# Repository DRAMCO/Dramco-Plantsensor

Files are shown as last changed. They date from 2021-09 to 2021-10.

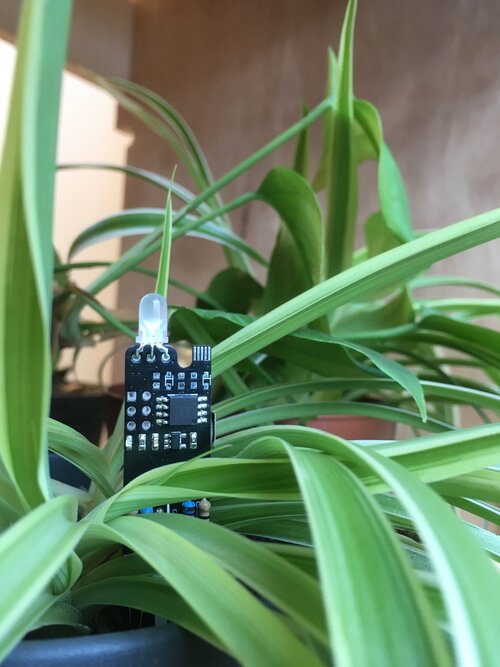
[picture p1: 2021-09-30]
Hardware/Pictures/Picture 2.jpg

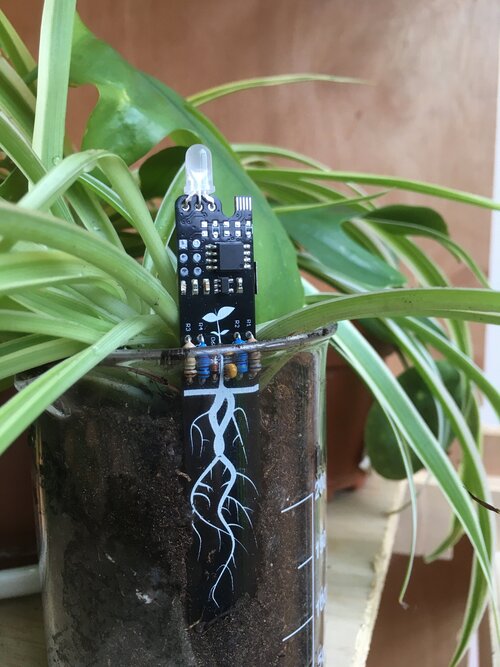
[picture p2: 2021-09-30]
Hardware/Pictures/Picture 1.jpg

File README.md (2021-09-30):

# Dramco Plantsensor
Blinking plant sensor

## How it works
The Dramco Plantsensor measures the moisture level of the soil every 30 seconds. When the soil is dry, the green LED will start blinking (first rapidly to get your attention, after a while it will slow down to every 30 seconds). The battery is running low when the red LED also starts blinking. If you have the rechargeable version, you can recharge using the micro USB connection on top. If not, replace the battery (you can also power the sensor of a USB cable). 

## How to assemble
When you get your Dramco Plantsensor, some components still need to be soldered. Solder all through hole components to complete the sensor. More information in this pdf. Don't forget to add a battery. 

## How to program
To program the Dramco Plantsensor, you'll need a [Dramco Uno as ATTINY85 programmer](https://create.arduino.cc/projecthub/arjun/programming-attiny85-with-arduino-uno-afb829), some [POGO pins](https://benl.rs-online.com/web/p/test-pins/1613648/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) and the [Arduino IDE](https://www.arduino.cc/en/software) installed. The pinout of the programming pads, is shown in the schematics. Adapt and use the following command to program: 
 ```
 "C:\Program Files (x86)\Arduino\hardware\tools\avr/bin/avrdude" -C"C:\Program Files (x86)\Arduino\hardware\tools\avr/etc/avrdude.conf" -v -pattiny85 -cstk500v1 -PCOM4 -b19200 -Uflash:w:"Soil_sensor.hex":i -U lfuse:w:0xF1:m -U hfuse:w:0x57:m -U efuse:w:0xFE:m
 ```
(!) This command disables the RESET pin of the ATTINY85, use only if you have a [high voltage flash programmer](https://td0g.ca/2020/04/13/high-voltage-flash-programming-on-attiny85/).

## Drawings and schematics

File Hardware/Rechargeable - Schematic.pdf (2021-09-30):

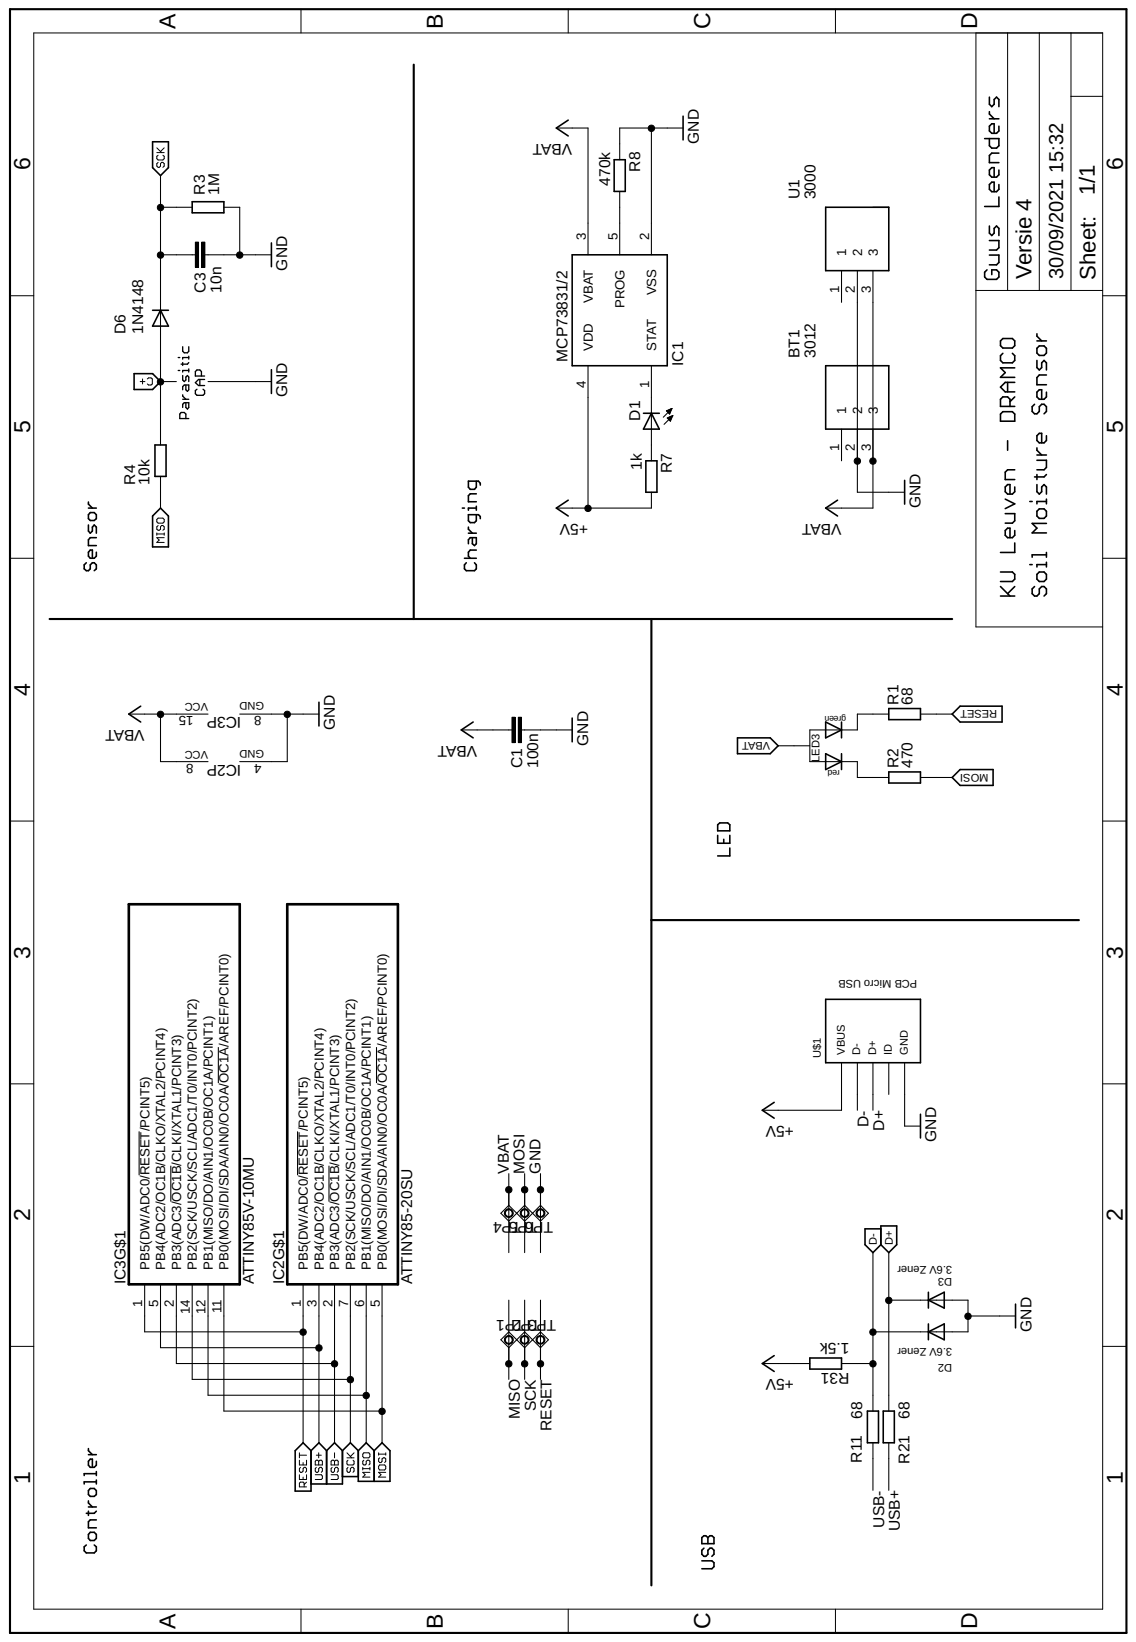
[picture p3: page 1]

5 IC1 D1 R7 R8 PB0(MOSI/DI/SDA/AIN0/OC0A/OC1A/AREF/PCINT0) 5 PB1(MISO/DO/AIN1/OC0B/OC1A/PCINT1) 6 PB2(SCK/USCK/SCL/ADC1/T0/INT0/PCINT2) 7 PB3(ADC3/OC1B/CLKI/XTAL1/PCINT3) 2 PB4(ADC2/OC1B/CLKO/XTAL2/PCINT4) 3 PB5(DW/ADC0/RESET/PCINT5) 1 IC2G$1 VCC GND

3 U1 R4 D6 C3 R3 R2LED3 R1 GND USB- USB+ MOSI

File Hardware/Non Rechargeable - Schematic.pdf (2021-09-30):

Sheet: 1/1 ABCD | 1 | 2 | 3 | 4 | 5 | 6 | ABCD 1 | 2 | 3 | 4 | 5 | 6 red | green

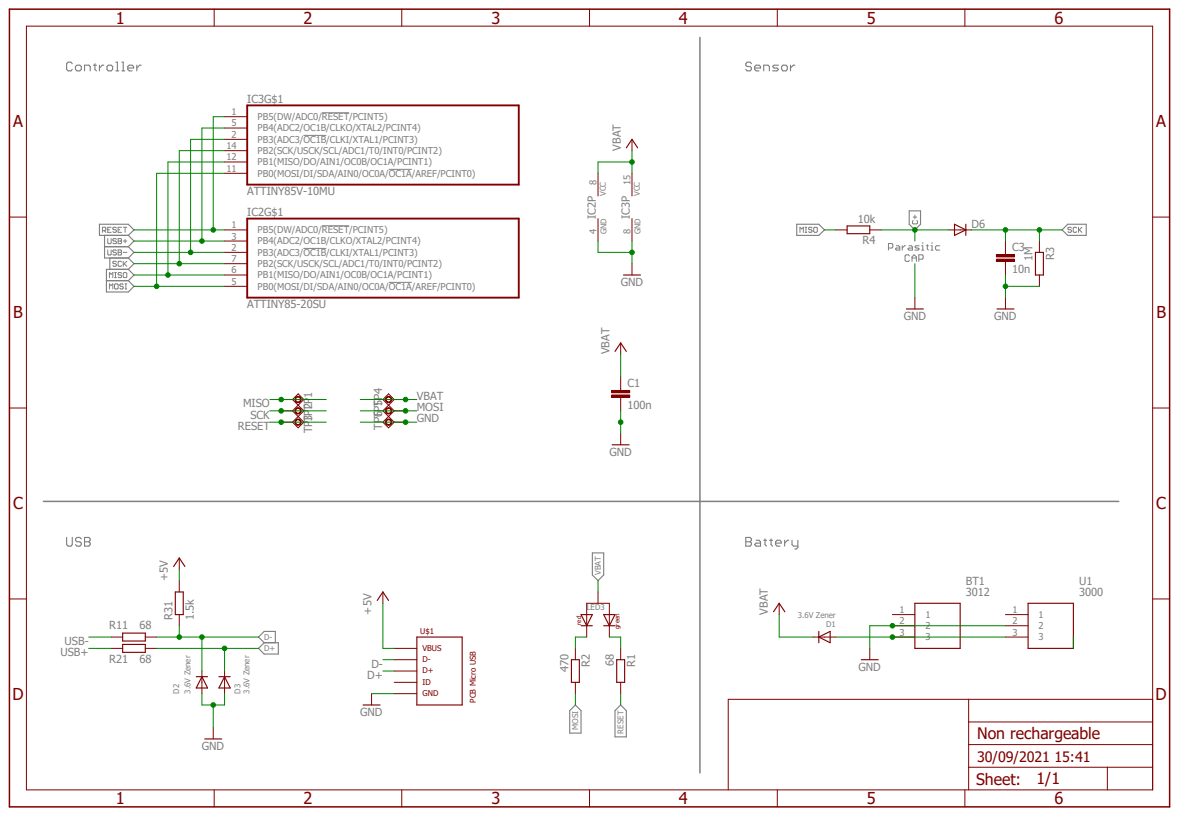
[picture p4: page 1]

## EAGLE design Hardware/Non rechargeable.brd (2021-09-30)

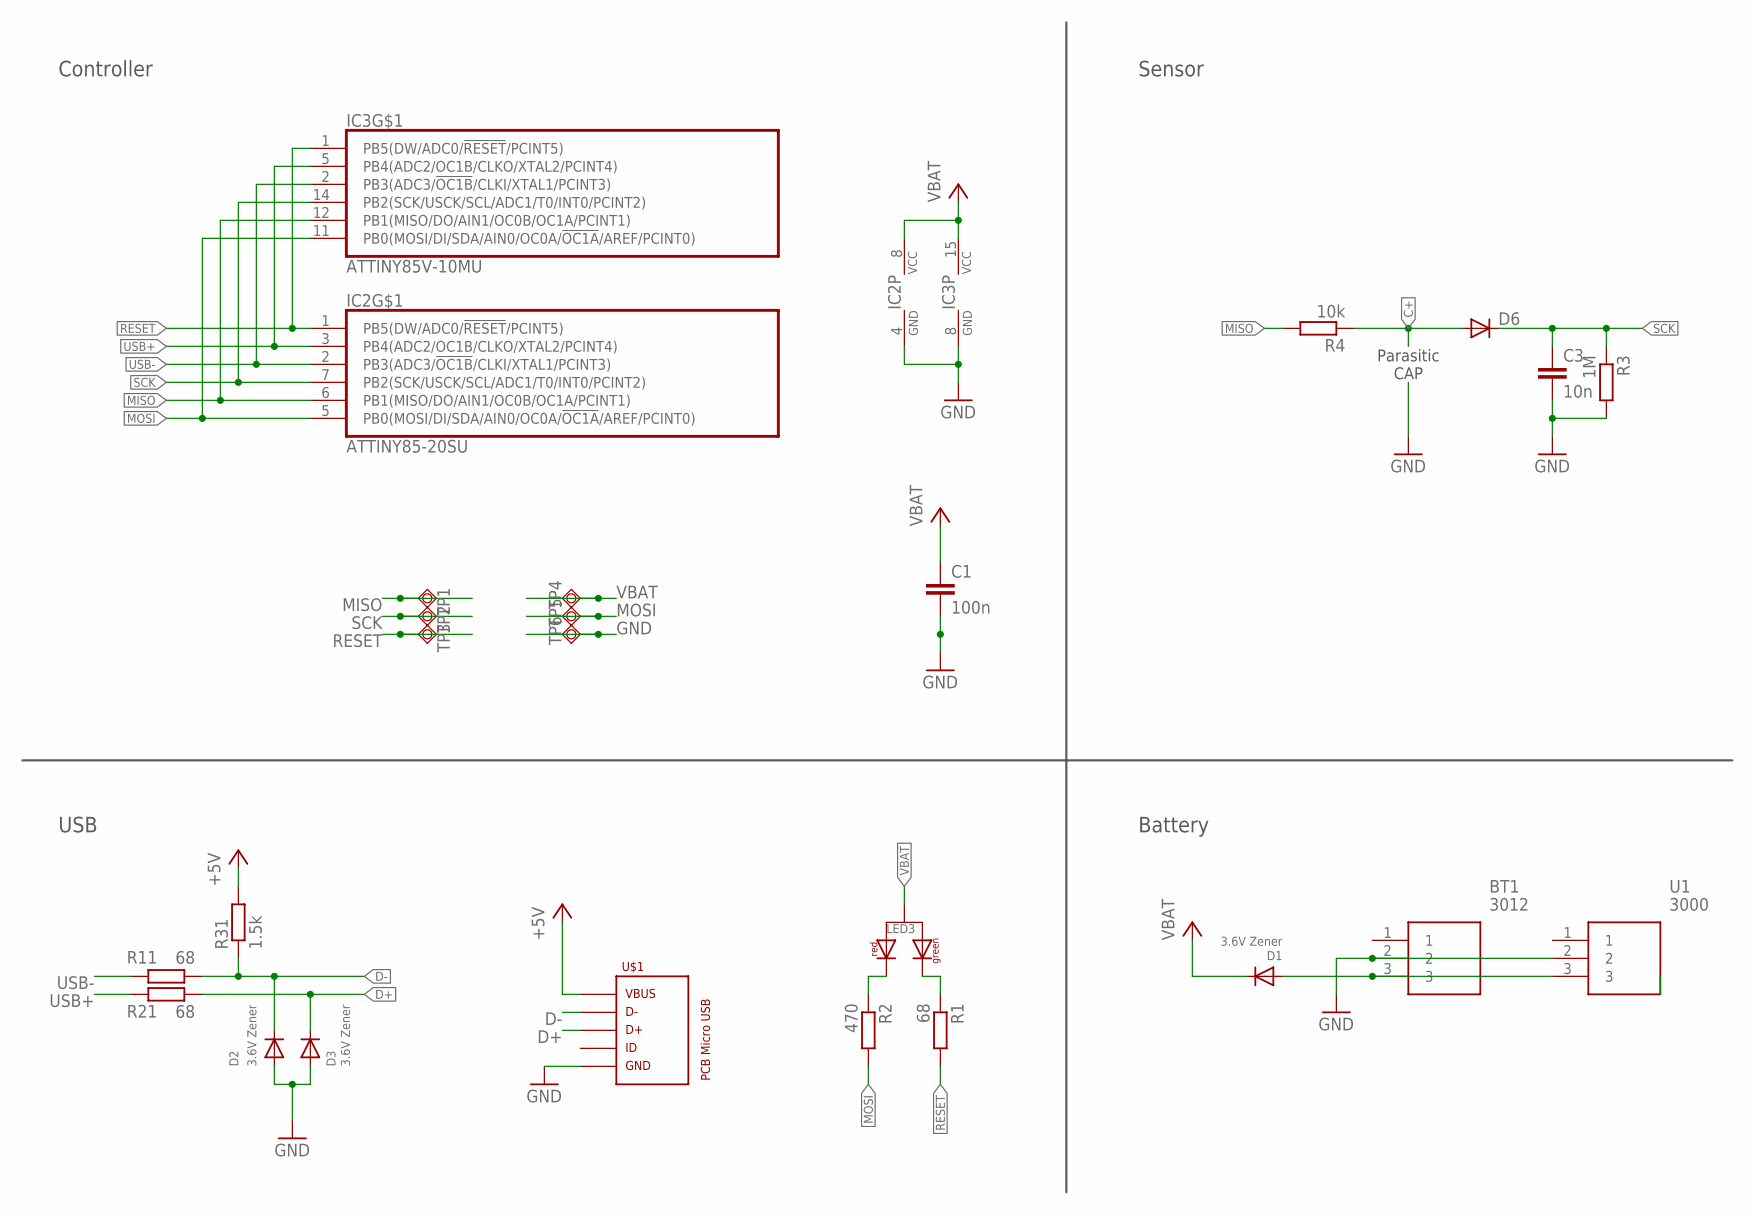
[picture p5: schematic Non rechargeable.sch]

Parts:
BT1: 3012
C1: 100n; C0603
C3: 10n; C025-024X044
D1, D2, D3: 3.6V Zener; SOD-323F
D6: DIODE-D-5; D-5
IC2: ATTINY85-20SU; 8S2
IC3: ATTINY85V-10MU; QFN20_4X4_0.50
LED3: KPBA-3010SURKCGKC3MM; 3MMLED
R1: 68; 0204/7
R2: 470; 0204/7
R3: 1M; 0204/7
R4: 10k; 0204/7
R11, R21: 68; R0603
R31: 1.5k; R0603
TP1, TP2, TP3, TP4, TP5: TPSQTP15R; TP15R
TP6: TPSQTP15SQ; TP15SQ
U1: 3000
U$1: PCB_MICRO_USB_BSS_3; USB_TYPE_B_SS_3

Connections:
C+: D6.A, R4.1
D+: D3.C, R21.1, U$1.3
D-: D2.C, R11.1, R31.1, U$1.2
GND: BT1.2, C1.2, C3.2, D2.A, D3.A, IC2.4 (GND), IC3.8 (GND), R3.2, TP6.TP, U1.2, U$1.5
MISO: IC2.6 (PB1(MISO/DO/AIN1/OC0B/OC1A/PCINT1)), IC3.12 (PB1(MISO/DO/AIN1/OC0B/OC1A/PCINT1)), R4.2, TP1.TP
MOSI: IC2.5 (PB0(MOSI/DI/SDA/AIN0/OC0A/!OC1A!/AREF/P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), IC3.11 (PB0(MOSI/DI/SDA/AIN0/OC0A/!OC1A!/AREF/P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), R2.2, TP5.TP
unnamed: LED3.-2, R1.1
unnamed: LED3.-1, R2.1
RESET: IC2.1 (PB5(DW/ADC0/!RESET!/PCINT5)), IC3.1 (PB5(DW/ADC0/!RESET!/PCINT5)), R1.2, TP3.TP
SCK: C3.1, D6.C, IC2.7 (PB2(SCK/USCK/SCL/ADC1/T0/INT0/PCINT2)), IC3.14 (PB2(SCK/USCK/SCL/ADC1/T0/INT0/PCINT2)), R3.1, TP2.TP
USB+: IC2.3 (PB4(ADC2/OC1B/CLKO/XTAL2/PCINT4)), IC3.5 (PB4(ADC2/OC1B/CLKO/XTAL2/PCINT4)), R21.2
USB-: IC2.2 (PB3(ADC3/!OC1B!/CLKI/XTAL1/PCINT3)), IC3.2 (PB3(ADC3/!OC1B!/CLKI/XTAL1/PCINT3)), R11.2
VB: BT1.3, D1.A, U1.3
VBAT: C1.1, D1.C, IC2.8 (VCC), IC3.15 (VCC), LED3.+, R31.2, TP4.TP, U$1.1

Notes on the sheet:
Controller
USB
Battery
Parasitic CAP
Sensor

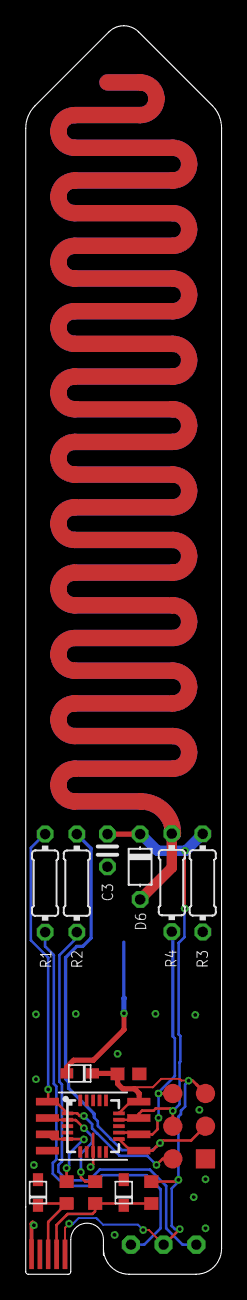
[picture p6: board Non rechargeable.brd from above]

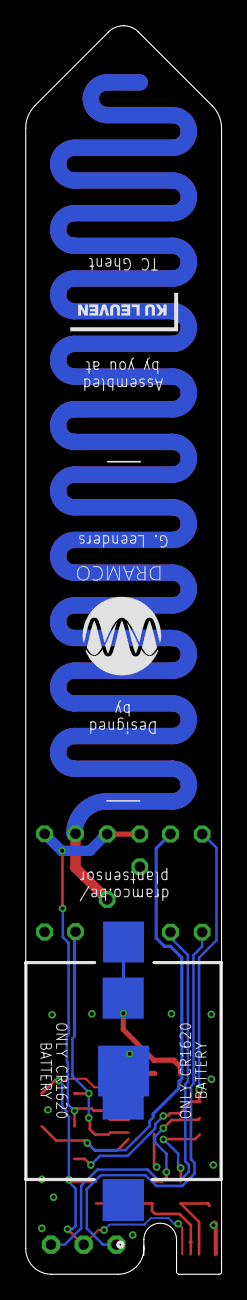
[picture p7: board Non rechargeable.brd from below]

Board: 2 copper layers, 15.2 x 97.0 mm, 25 parts (2 on the bottom side), 14 nets.

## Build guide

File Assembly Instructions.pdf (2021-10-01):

## D R A M C O P L A N T S E N S O R

Assembly instructions

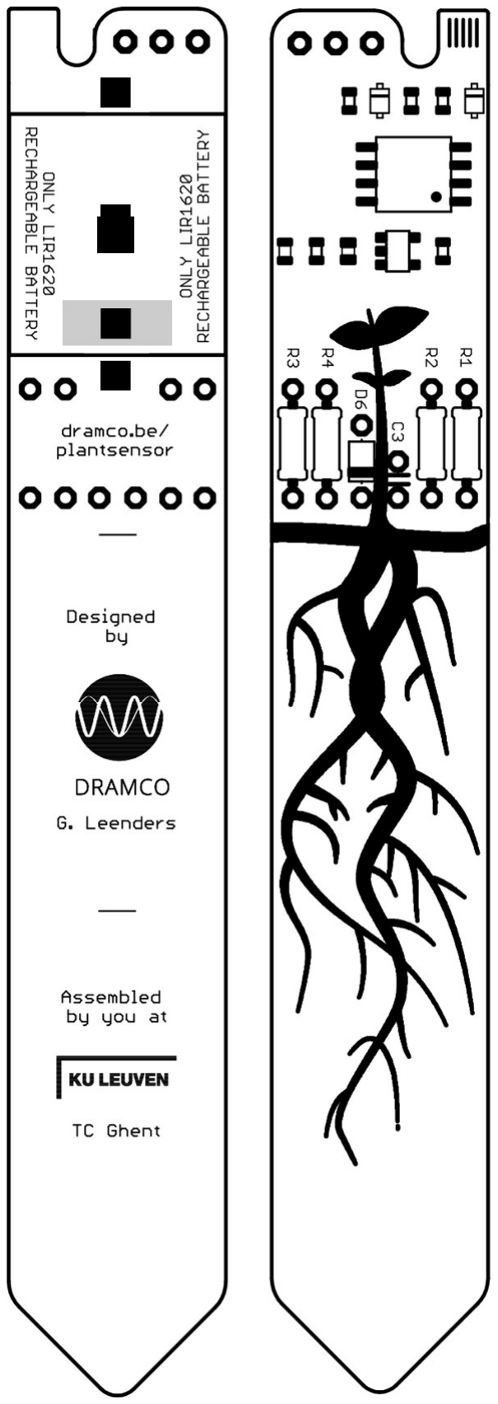
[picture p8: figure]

R1: 68 Ω

R2: 470 Ω

C3: 1 nF
102

R3: 1 MΩ

R4: 10 kΩ

D6: 1N4148
Mind polarity

LED: Red/Green LED
Mind polarity (flat side to USB)

USB connection

1620 Battery with holder
See print for rechargeable LIR1620 or non-rechargeable CR1620

Cover pad with piece of tape

## D R A M C O P L A N T S E N S O R

Bill of materials (and checklist)

- | Bat | Battery holder | 1620
- | R1 | Resistor | 68 Ω
- | R2 | Resistor | 470 Ω
- | R3 | Resistor | 1 MΩ
- | R4 | Resistor | 10 kΩ
- | D6 | Diode | 1N4148
- | C3 | Capacitor | 1 nF
- | LED | Red/Green LED | (Flat side facing USB)

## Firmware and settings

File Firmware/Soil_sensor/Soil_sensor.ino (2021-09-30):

#include <avr/sleep.h>
#include <avr/power.h>
#include <avr/wdt.h>

#define MEASURE_DELAY   30000UL
#define PING_DELAY_MAX  30000UL
#define PING_DELAY_MIN  1000UL

#define MEASURE_THRESHOLD_4 180//640
#define MEASURE_THRESHOLD_3 170//150
#define MEASURE_THRESHOLD_2 160//640

#define LED_PIN_GREEN   0
#define LED_PIN_RED     5
#define USB_P           4
#define USB_N           3
#define MEASURE_C_PIN   2
#define MEASURE_C_ADC   1
#define MEASURE_PWM_PIN 1

volatile unsigned long measurementTimer = 0;
volatile unsigned int pingTimer = 0;

volatile uint16_t lastMeasurement = 0;
uint16_t currentPingDelay = 0;

uint8_t mcucr1, mcucr2;
int vcc = 0;

uint8_t measure_threshold = MEASURE_THRESHOLD_2;

void setup() {
  pinMode(MEASURE_PWM_PIN, OUTPUT);
  pinMode(LED_PIN_GREEN, OUTPUT);
  pinMode(LED_PIN_RED, OUTPUT);

  digitalWrite(LED_PIN_GREEN, HIGH); // LED is active LOW
  digitalWrite(LED_PIN_RED, HIGH); // LED is active LOW
  digitalWrite(MEASURE_PWM_PIN, LOW);

  currentPingDelay = PING_DELAY_MIN;
  vcc = measureVCC();
  
  ACSR |= _BV(ACD);                         //disable the analog comparator

  measurementTimer = MEASURE_DELAY+1;
  pingTimer = currentPingDelay+1;
}


void loop() {
  
  if(measurementTimer >= MEASURE_DELAY){
    
    vcc = measureVCC();
    if(vcc >= 4000){
      measure_threshold = MEASURE_THRESHOLD_4;
    }else if(vcc >= 3000){
      measure_threshold = MEASURE_THRESHOLD_3;
    }else{
      measure_threshold = MEASURE_THRESHOLD_2;
    }

    uint8_t measurement = measureSoilMoisture();
    measurementTimer = 0;
    if(measurement > measure_threshold && lastMeasurement < measure_threshold){
      // Dry soil, and we went from wet to dry
      currentPingDelay = PING_DELAY_MIN;
    }
    else if(measurement <= measure_threshold){
      // Wet soil, no need to go blinking
      currentPingDelay = PING_DELAY_MAX;
    }
        lastMeasurement = measurement;
  }
  if(pingTimer >= currentPingDelay){
    if(lastMeasurement > measure_threshold){
      for(uint8_t nBlinks = 0; nBlinks < 3; nBlinks++){
        digitalWrite(LED_PIN_GREEN, LOW);
        sleepNow(125);
        digitalWrite(LED_PIN_GREEN, HIGH);
        sleepNow(125);
      }
      currentPingDelay += 1000;
      if(currentPingDelay > PING_DELAY_MAX){
        currentPingDelay = PING_DELAY_MAX;
      }
    }else{
      digitalWrite(LED_PIN_GREEN, HIGH);
    }
    if(vcc <= 2800){
      for(uint8_t nBlinks = 0; nBlinks < 3; nBlinks++){
        digitalWrite(LED_PIN_RED, LOW);
        sleepNow(125);
        digitalWrite(LED_PIN_RED, HIGH);
        sleepNow(125);
      }
    }
    
    pingTimer = 0;
  }
  //uint16_t sleep = currentPingDelay;
  if(currentPingDelay >= 8000UL){
    sleepNow(8000);
  }else if(currentPingDelay >= 4000UL){
    sleepNow(4000);
  }else if(currentPingDelay >= 2000UL){
    sleepNow(2000);
  }else{
    sleepNow(1000);
  }
}

uint8_t measureSoilMoisture(){
  // Set PWM output
  // Note: PWM frequency must be set to 64kHz. Change:
  //       in arduino-1.x/hardware/digispark/cores/tiny/wiring.c MS_TIMER_TICK_EVERY_X_CYCLES to 1
  //       in arduino-1.x/hardware/digispark/cores/tiny/core_build_options.h FAVOR_PHASE_CORRECT_PWM  to 0 

  analogWrite(MEASURE_PWM_PIN,40);
  delay(50);
  uint8_t sensorValue = (uint8_t)(analogRead(MEASURE_C_ADC)>>2); // read ADC1
  analogWrite(MEASURE_PWM_PIN,0);
  return sensorValue;

}

int measureVCC(){
  uint8_t mux = ADMUX;
  uint8_t sra = ADCSRA;
  
  //reads internal 1V1 reference against VCC
  ADMUX = _BV(MUX3) | _BV(MUX2); // For ATtiny85/45
  delay(2); // Wait for Vref to settle
  ADCSRA |= _BV(ADSC); // Convert
  while (bit_is_set(ADCSRA, ADSC));
  uint8_t low = ADCL;
  unsigned int val = (ADCH << 8) | low;
  //discard previous result
  ADCSRA |= _BV(ADSC); // Convert
  while (bit_is_set(ADCSRA, ADSC));
  low = ADCL;
  val = (ADCH << 8) | low;

  ADMUX = mux;
  ADCSRA = sra;
  
  return ((long)1024 * 1100) / val;  
}

void sleepNow (uint16_t wdt_delay){

  ADCSRA &= ~_BV(ADEN);                     //disable ADC
  set_sleep_mode(SLEEP_MODE_PWR_DOWN);
  sleep_enable();
  
  wdtEnable(wdt_delay);              //start the WDT
  
  //turn off the brown-out detector.
  //must have an ATtiny45 or ATtiny85 rev C or later for software to be able to disable the BOD.
  //current while sleeping will be <0.5uA if BOD is disabled, <25uA if not.
  cli();
  mcucr1 = MCUCR | _BV(BODS) | _BV(BODSE);  //turn off the brown-out detector
  mcucr2 = mcucr1 & ~_BV(BODSE);
  MCUCR = mcucr1;
  MCUCR = mcucr2;
  sei();                         //ensure interrupts enabled so we can wake up again
  sleep_cpu();                   //go to sleep
                                 //----zzzz----zzzz----zzzz----zzzz
  cli();                         //wake up here, disable interrupts
  sleep_disable();
  wdtDisable();                  //don't need the watchdog while we're awake
  sei();                         //enable interrupts again (but INT0 is disabled above)


  ADCSRA |= _BV(ADEN);                     //enable ADC
  
  measurementTimer += wdt_delay;
  pingTimer += wdt_delay;
}

void wdtEnable(uint16_t wdt_delay){
    wdt_reset();
    cli();
    MCUSR = 0x00;
    WDTCR |= _BV(WDCE) | _BV(WDE);
    WDTCR = _BV(WDIE);
    switch(wdt_delay){
      case 8000: {
        WDTCR |= (1 << WDP3) | (0 << WDP2) | (0 << WDP1) | (1 << WDP0); // 8 seconds sleep before WDT
      }break;
      case 4000: {
        WDTCR |= (1 << WDP3) | (0 << WDP2) | (0 << WDP1) | (0 << WDP0);
      }break;
      case 2000: {
        WDTCR |= (0 << WDP3) | (1 << WDP2) | (1 << WDP1) | (1 << WDP0);
      }break;
      case 1000: {
        WDTCR |= (0 << WDP3) | (1 << WDP2) | (1 << WDP1) | (0 << WDP0);
      }break;
      case 500: {
        WDTCR |= (0 << WDP3) | (1 << WDP2) | (0 << WDP1) | (1 << WDP0);
      }break;
      case 250: {
         WDTCR |= (0 << WDP3) | (1 << WDP2) | (0 << WDP1) | (0 << WDP0);
      }break;
      case 125: {
        WDTCR |= (0 << WDP3) | (0 << WDP2) | (1 << WDP1) | (1 << WDP0);
      }break;
      case 64: {
        WDTCR |= (0 << WDP3) | (0 << WDP2) | (1 << WDP1) | (0 << WDP0);
      }break;
      case 32: {
        WDTCR |= (0 << WDP3) | (0 << WDP2) | (0 << WDP1) | (1 << WDP0);
      }break;
      case 16: {
        WDTCR |= (0 << WDP3) | (0 << WDP2) | (0 << WDP1) | (0 << WDP0);
      };
      default: {
        WDTCR |= (0 << WDP3) | (1 << WDP2) | (1 << WDP1) | (0 << WDP0);
      };
    }  
    sei();
}

void wdtDisable(void){
    wdt_reset();
    cli();
    MCUSR = 0x00;
    WDTCR |= _BV(WDCE) | _BV(WDE);
    WDTCR = 0x00;
    sei();
}

ISR(WDT_vect) {
  wdt_disable();
}
